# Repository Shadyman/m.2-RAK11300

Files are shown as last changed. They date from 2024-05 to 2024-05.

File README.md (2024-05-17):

# RAK11300 LoRa Module on m.2 Key A-E

This is a board in the _m.2 Key A-E_ form factor to allow the use of the [RAK11300](https://docs.rakwireless.com/Product-Categories/WisDuo/RAK11300-Module/) module. 

RAK11300 contains an RP2040 microcontroller, an SX1262 and supporting circuitry on a castellated green PCB. The RAK11300 provides 8xx-9xxMhz-Band communications, depending on the model used. The RAK11300L variant may be substituted, and operates on 433 or 470 Mhz depending on the model.

# m.2 Pins Used
- PERST0n
- Vendor-Defined 38,40,42
- W_DISABLEn
- LED_1n
- LED_2n
- USB+/-

# RAK11300 Pins Used
- RESETn
- BOOT
- SWCLK/SWDIO
- GPIO6, 9, 22, 23, 24
- USB_DP/_DM

# Project Status
- [x] Schematic Creation
- [ ] PCB Creation
  - [X] PCB Layout
  - [ ] TODO: Verify BOOT/SWCLK/SWDIO pinout vs other modules for ease of use
  - [ ] TODO: Calculate LED series resistors where needed
- [ ] Initial PCB Test Run
  - [ ] Finalize BOM
  - [ ] Assembly
- [ ] PCB Testing

# References
- [RAK11300 Item Page - RAK Store](https://store.rakwireless.com/products/wisduo-lpwan-module-rak11300)
- [RAK11300 WisDuo LPWAN Module - Reference Documents](https://docs.rakwireless.com/Product-Categories/WisDuo/RAK11300-Module/Overview/)
  - Backup snapshot of reference documents and .STL file available in /Documents/
- [SX1262 Product Page - Semtech](https://www.semtech.com/products/wireless-rf/lora-connect/sx1262)

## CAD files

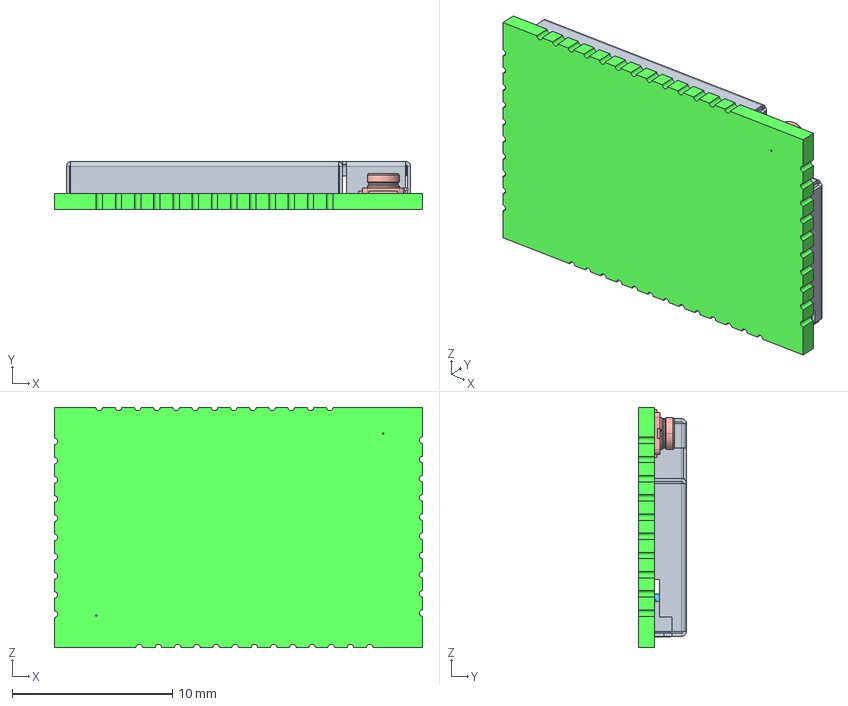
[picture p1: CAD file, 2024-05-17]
Documents/3D_RAK11300.stp
23.0 x 3.00 x 15.0 mm
PWB-RAK11300
IPEX-FEMALE
RAKU70580016
1610C00D

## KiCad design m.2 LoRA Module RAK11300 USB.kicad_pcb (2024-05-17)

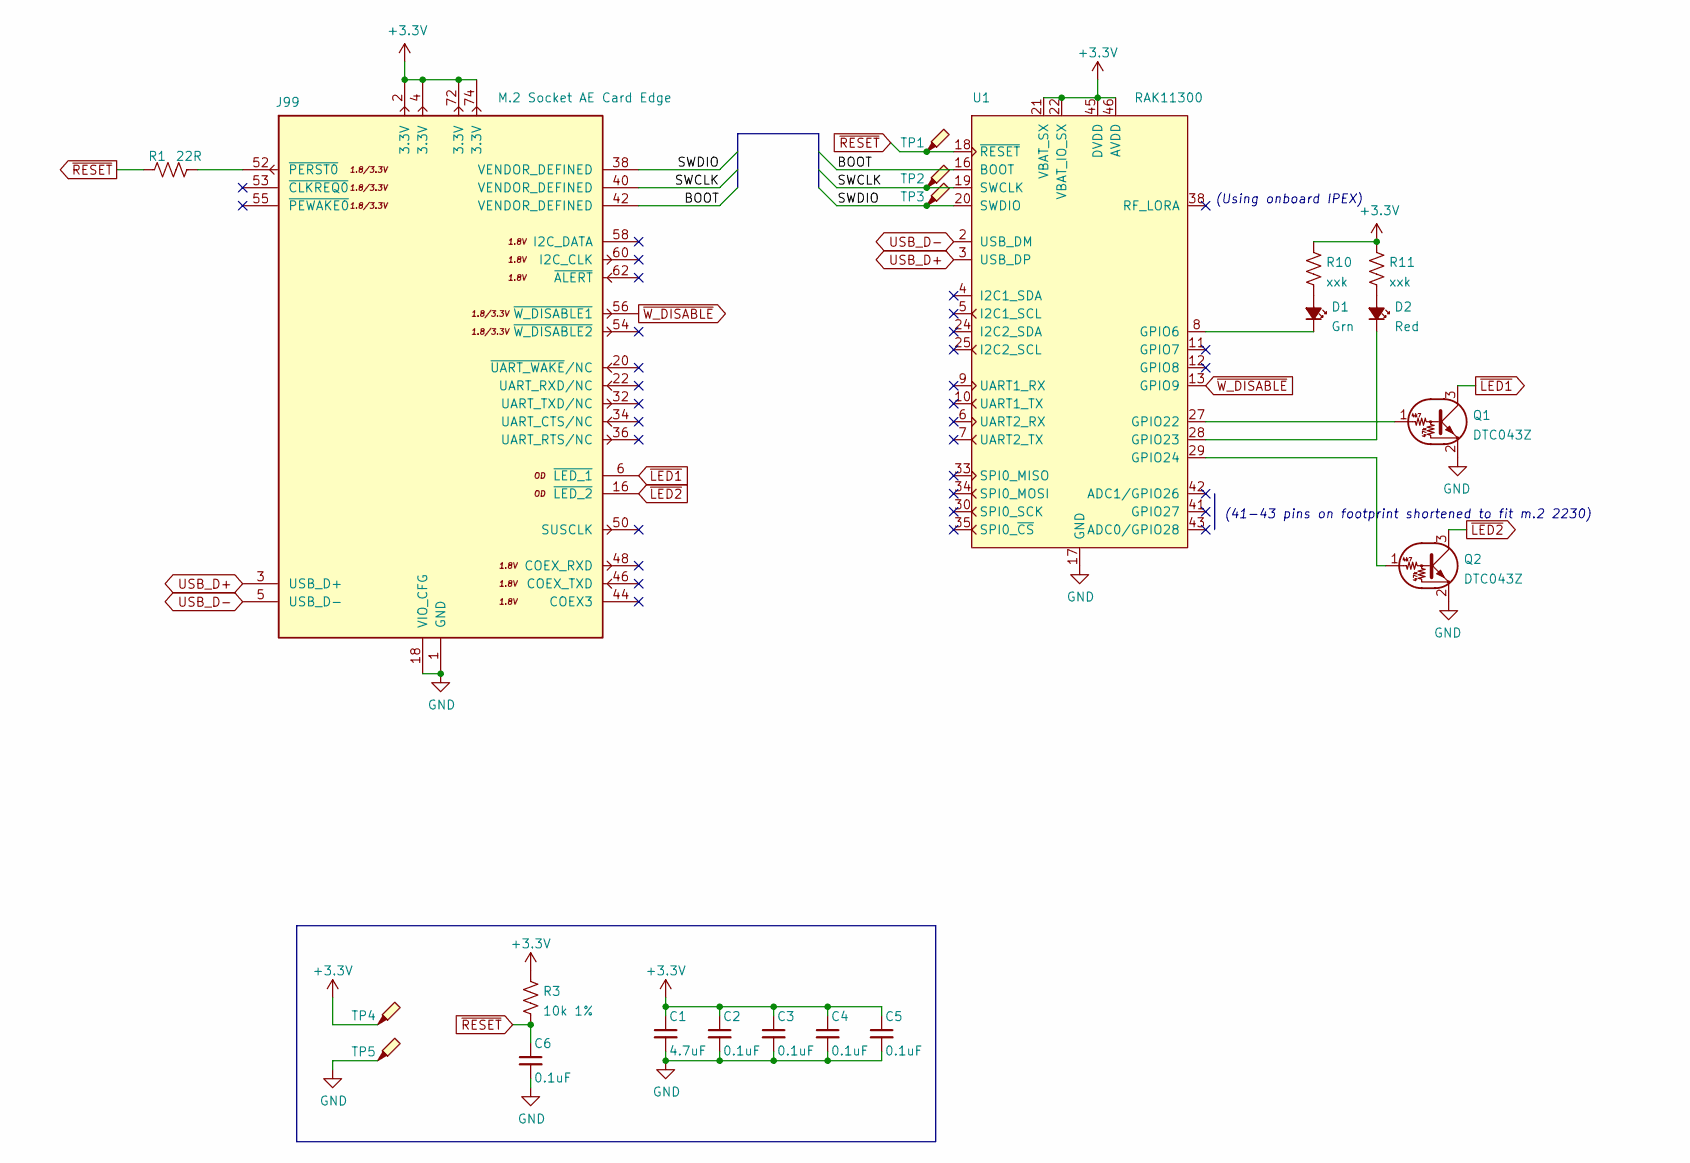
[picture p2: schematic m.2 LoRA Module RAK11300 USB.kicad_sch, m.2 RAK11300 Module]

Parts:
C1: 4.7uF; C_0603_1608Metric
C2, C3, C4, C5, C6: 0.1uF; C_0402_1005Metric
D1: Grn; LED_0603_1608Metric; MPN 19-217-R6C-AL1M2VY-3T
D2: Red; LED_0603_1608Metric; MPN 19-217-G7C-AN1P2-3T
J99: M.2 Socket AE Card Edge; m2-padKeyAE
Q1, Q2: DTC043Z; SOT-416; MPN DTC043ZEBTL
R1: 22R; R_0402_1005Metric
R3: 10k 1%; R_0402_1005Metric
R10, R11: xxk; R_0402_1005Metric
TP1, TP2, TP3, TP4, TP5: TestPoint_Probe; TestPoint_Pad_D1.5mm
U1: RAK11300

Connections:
+3V3: C1.1, C2.1, C3.1, C4.1, C5.1, J99.2 (3.3V), J99.4 (3.3V), J99.72 (3.3V), J99.74 (3.3V), R3.1, R10.1, R11.1, TP4.1, U1.21 (VBAT_SX), U1.22 (VBAT_IO_SX), U1.45 (DVDD), U1.46 (AVDD)
/BOOT: J99.42 (VENDOR_DEFINED), U1.16 (BOOT)
/I2C1_SCL: U1.5 (I2C1_SCL)
/I2C1_SDA: U1.4 (I2C1_SDA)
/SWCLK: J99.40 (VENDOR_DEFINED), TP2.1, U1.19 (SWCLK)
/SWDIO: J99.38 (VENDOR_DEFINED), TP3.1, U1.20 (SWDIO)
GND: C1.2, C2.2, C3.2, C4.2, C5.2, C6.2, J99.1 (GND), J99.7 (GND), J99.18 (VIO_CFG), J99.33 (GND), J99.39 (GND), J99.45 (GND), J99.51 (GND), J99.57 (GND), J99.63 (GND), J99.69 (GND), J99.75 (GND), Q1.2 (E), Q2.2 (E), TP5.1, U1.14 (GND), U1.17 (GND), U1.23 (GND), U1.36 (GND), U1.37 (GND), U1.40 (GND), U1.44 (GND)
unnamed: D1.1 (K), U1.8 (GPIO6)
unnamed: D1.2 (A), R10.2
unnamed: D2.1 (K), U1.28 (GPIO23)
unnamed: D2.2 (A), R11.2
unnamed: J99.52 (~PERST0), R1.1
unnamed: Q1.1 (B), U1.27 (GPIO22)
unnamed: Q2.1 (B), U1.29 (GPIO24)
USB_D+: J99.3 (USB_D+), U1.3 (USB_DP)
USB_D-: J99.5 (USB_D-), U1.2 (USB_DM)
~LED1: J99.6 (~LED_1), Q1.3 (C)
~LED2: J99.16 (~LED_2), Q2.3 (C)
~RESET: C6.1, R1.2, R3.2, TP1.1, U1.18 (~RESET)
~W_DISABLE: J99.56 (~W_DISABLE1), U1.13 (GPIO9)

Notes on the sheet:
(Using onboard IPEX)
(41-43 pins on footprint shortened to fit m.2 2230)

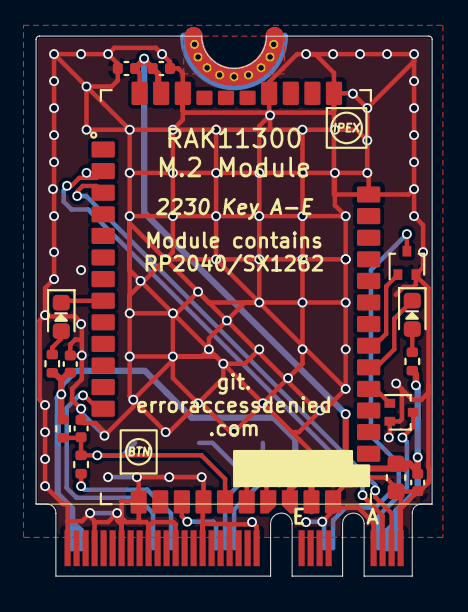
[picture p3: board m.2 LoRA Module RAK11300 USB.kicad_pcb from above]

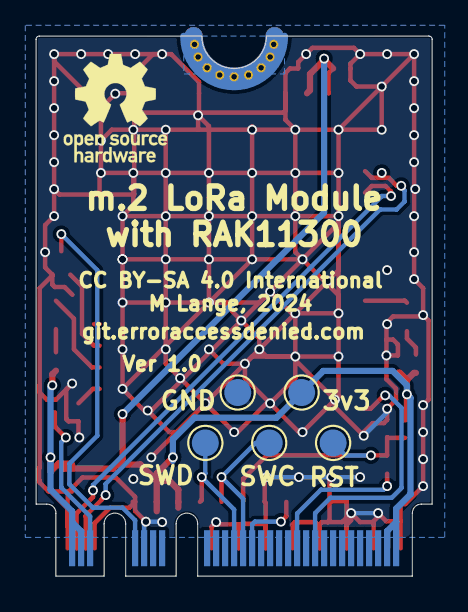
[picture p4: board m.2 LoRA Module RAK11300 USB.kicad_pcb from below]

Board: 2 copper layers, 22.0 x 30.0 mm, 22 parts (5 on the bottom side), 18 nets.

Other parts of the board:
J98: m.2-ngff-outline-copper

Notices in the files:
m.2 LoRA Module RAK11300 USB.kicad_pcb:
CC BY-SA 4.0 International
